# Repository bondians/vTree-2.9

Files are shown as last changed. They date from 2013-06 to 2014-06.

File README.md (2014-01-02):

vTree 2.9
==========

This is mokus's version of the XBee-controlled RGB LED floodlight.  This repository includes the latest hardware and firmware designs.  If cayuse is interested the firmware can be fairly easily ported to his hardware as well.

Hardware
=========

In the `schematics/` directory, there are several gEDA schematics and layouts.  The main ones of interest are:

 * `schematics/standalone-power-section`:  This is a small board with a power regulator, 3 MOSFETS, and associated resistors and capacitors.  Just add an MCU and IR receiver of your choice.

 * `schematics/xmega-xbee-rgb-led`: This is mokus's current prototype - it's a single board with all the stuff from the "standalone power section" plus an XMEGA 8E5 and headers to directly attach an XBee (non-pro only, for space reasons).

For cost reasons, all current hardware makes a pretty heinous compromise - the 3 LED channels share a single driver.  The plan is to attempt to correct for this in software (this is partially implemented and looks tractable).  If that proves infeasible, future versions may be modified to use a voltage-regulated supply and a separate 3-channel current regulation stage.

Firmware
=========

The firmware currently targets only the XMEGA E5, but should be pretty easy to port to any AVR.  It is also currently pretty simple, since I'm still mostly working on getting the hardware built.  It has 2 control inputs - an XBee module and an IR receiver.  The XBee (series 1 or 2, both work) is expected to be configured for 9600 baud, 8N1, API mode with escape codes.  The IR codes are hard-coded and the current values are probably not useful to anyone but me.

The XBee message format is very simple (and very likely to change soon).  Any message with 6 or more bytes is interpreted as a command to set the R, G and B channels (respectively) to the first 6 bytes of the message, interpreted as a series of big-endian 16-bit words.

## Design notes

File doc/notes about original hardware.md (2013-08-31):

Some notes about the original hardware we're hacking up here...

Parts on the control board:

- SOIC-8 I2C EEPROM, marked:

        Atmel306
        24C02BN
        SU27 D

- Unmarked SOIC-8 IC
    (presumed MCU, not able to identify by pinout)

- n-channel enhancement mode mosfet (si2302)
    - marked `A2sHB`
    - smd "331" (330 ohm) resistor on gate of each, in series to mcu
    - no pull-down on gates... the thing flashes when plugged in

- regulator
    - marked `78L05 d3`
    - rated 5V, 100mA
    - 100 uF on input, 47 uF on output

- IR receiver
    - very clearly marked `3144S` but i can't find a datasheet or any other info about it
    - mated to a ~4" cable via a very small pcb inside some heat-shrink (pcb is purely structural, no logic or additional components)
    - works at 3.3v

- Other parts:
    - capacitor, 12 pF
    - capacitor, 1 nF
    - capacitor, 100 nF
    - resistor, 15 ohm (appears to be 2W carbon-film type, or maybe 5W metal-film)
    - inductor/ferrite bead (probably, it's in series from regulator output to 5v power)

Other observations (some stuff i could see with my multimeter, and some calculations based on the assumption that the driver's claimed 600mA current regulation is correct):

 - light off:
    - ~48 kHz ripple (at + side of LED module)
    - input voltage 12.12V

- light full-on white:
    - input voltage 8.75
    - 155.3 Hz pwm on red, green - blue appears to be fully on
    - voltage drop across:
        - red:   6.21
        - R+red: 8.63
        - R:     2.42
        - green: 8.63
        - blue:  8.65
    - calculations:
        - total power:
            5.25 W
        - current through:
            - R, red:   161 mA
        - power through R: 390 mW
    
- light full-red:
    - ~ 138 kHz ripple
    - 155.3 Hz pwm on red, ripple on others
    - input voltage 11.68
    - voltage drop across:
        - red:   6.72
        - R+red: 11.45
        - green: 0.00
        - blue:  0.00
    - calculations:
        - total power (assuming 100% duty, which I think is wrong):
            7 W
        - current through:
            - R, red:   315.33333 mA
        - power through R: 1.49 W

- light full-green:
    - ~ 100 kHz ripple
    - 155.3 Hz pwm on green, ripple on others
    - input voltage 10.15
    - voltage drop across:
        - red:   4.51
        - R+red: 4.50
        - green: 9.94
        - blue:  1.76
    - calculations:
        - total power (assuming 100% duty, which I think is wrong):
            6.09 W

- light full-blue:
    - ~ 100 kHz ripple
    - momentary 155.3 Hz pwm on blue, then 0Hz (ripple on others).
    - input voltage 9.82
    - voltage drop across:
        - red:   3.68
        - R+red: 3.60
        - green: 6.28
        - blue:  9.68
    - calculations:
        - total power: 5.892 W

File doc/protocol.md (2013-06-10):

Current protocol (will likely change...):

1 byte 'sync' (or hardware-level break), 1 byte size (excluding size, sync and crc), 1-256 bytes payload (size 0 is interpreted as 256), 2 bytes CRC.  CRC polynomial TBD, prolly whatever's in the AVR libs.

overview of payload types:

    * enumerate: need to work out details, but there must be an enumeration scheme whereby the host, when initializing, can discover all lights and any new light, when initializing, will report itself to the host.  Net effect being that the host will always know what devices are attached.  'Device number', used in many other message types, is established here (it may be negotiated or, more likely, it may be an NVRAM-stored attribute of the device).  Devices also should be able to determine whether there is a host present.  Simplest scheme would probably be for all devices to send a heartbeat, with "host" devices using a different range of device numbers (or just one specified device number if it's fair to assume there is always at most one host).

    * get device info: given device number, device replies with immutable info about itself such as number of channels (maybe also topology info about physical groupings), basic description of what each channel does (color/hue/sat/brightness/generic pwm load/etc), etc.
    
    * set channel address: given a serial number/chan number pair, assigns a logical address.  This address should be remembered by the device across resets.
    
    * query channel address: given serial number/chan number pair, device reports what address is currently assigned to that channel.
    
    * set channel values: given a collection of channel addresses and/or device/chan number pairs, and a corresponding collection of channel levels, set the specified channels to the specified levels.
    
    * query channel value: given a channel address or device/chan pair, get the current value of the specified channel

    * IR code received: when a device receives an IR code, it sends its device number and the code.

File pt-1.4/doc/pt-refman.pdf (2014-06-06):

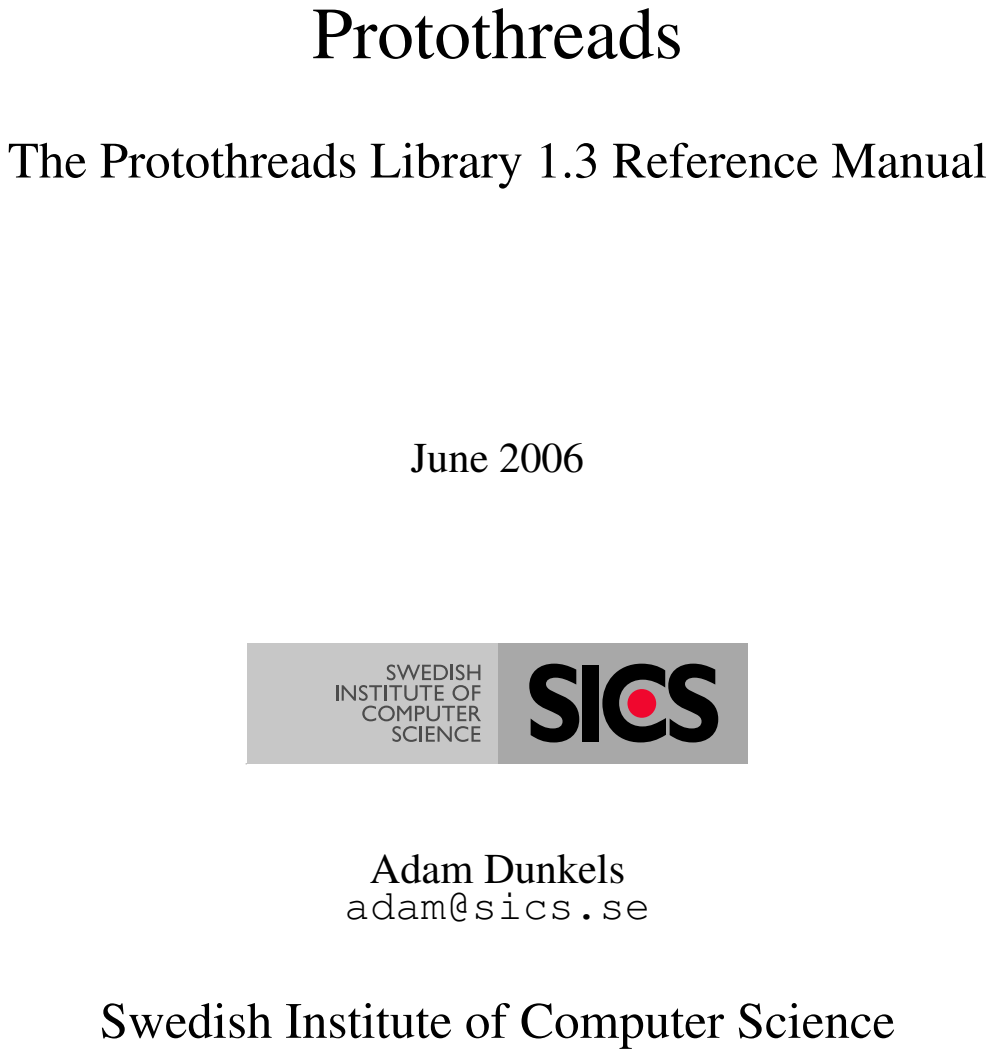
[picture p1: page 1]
Protothreads; June 2006

The Protothreads Library 1.3 Reference Manual

Adam Dunkels
adam@sics.se

Swedish Institute of Computer Science

CONTENTS | 1

## Contents

1 The Protothreads Library | 1
2 The Protothreads Library 1.4 Module Index | 3
3 The Protothreads Library 1.4 Hierarchical Index | 3
4 The Protothreads Library 1.4 Data Structure Index | 4
5 The Protothreads Library 1.4 File Index | 4
6 The Protothreads Library 1.4 Module Documentation | 4
7 The Protothreads Library 1.4 Data Structure Documentation | 25
8 The Protothreads Library 1.4 File Documentation | 25

## 1 The Protothreads Library

Author:
Adam Dunkels <adam@sics.se>

Protothreads are a type of lightweight stackless threads designed for severly memory constrained systems such as deeply embedded systems or sensor network nodes. Protothreads provides linear code execution for event-driven systems implemented in C. Protothreads can be used with or without an RTOS.

Protothreads are a extremely lightweight, stackless type of threads that provides a blocking context on top of an event-driven system, without the overhead of per-thread stacks. The purpose of protothreads is to implement sequential flow of control without complex state machines or full multi-threading. Protothreads provides conditional blocking inside C functions.

Main features:

- No machine specific code - the protothreads library is pure C
- Does not use error-prone functions such as longjmp()
- Very small RAM overhead - only two bytes per protothread
- Can be used with or without an OS
- Provides blocking wait without full multi-threading or stack-switching

Examples applications:

- Memory constrained systems
- Event-driven protocol stacks

Generated on Mon Oct 2 10:06:29 2006 for The Protothreads Library 1.4 by Doxygen

1.1 Authors | 2
- Deeply embedded systems
- Sensor network nodes

See also:
Example programs
Protothreads API documentation

The protothreads library is released under a BSD-style license that allows for both non-commercial and commercial usage. The only requirement is that credit is given.

More information and new version of the code can be found at the Protothreads homepage:

http://www.sics.se/∼adam/pt/ (http://www.sics.se/~adam/pt/)

### 1.1 Authors

The protothreads library was written by Adam Dunkels <adam@sics.se> with support from Oliver
Schmidt <ol.sc@web.de>.

### 1.2 Using protothreads

Using protothreads in a project is easy: simply copy the files pt.h, lc.h and lc-switch.h into the include files directory of the project, and #include "pt.h" in all files that should use protothreads.

### 1.3 Protothreads

Protothreads are a extremely lightweight, stackless threads that provides a blocking context on top of an event-driven system, without the overhead of per-thread stacks. The purpose of protothreads is to implement sequential flow of control without using complex state machines or full multi-threading. Protothreads provides conditional blocking inside a C function.

In memory constrained systems, such as deeply embedded systems, traditional multi-threading may have a too large memory overhead. In traditional multi-threading, each thread requires its own stack, that typically is over-provisioned. The stacks may use large parts of the available memory.

The main advantage of protothreads over ordinary threads is that protothreads are very lightweight: a protothread does not require its own stack. Rather, all protothreads run on the same stack and context switching is done by stack rewinding. This is advantageous in memory constrained systems, where a stack for a thread might use a large part of the available memory. A protothread only requires only two bytes of memory per protothread. Moreover, protothreads are implemented in pure C and do not require any machine-specific assembler code.

A protothread runs within a single C function and cannot span over other functions. A protothread may call normal C functions, but cannot block inside a called function. Blocking inside nested function calls is instead made by spawning a separate protothread for each potentially blocking function. The advantage of this approach is that blocking is explicit: the programmer knows exactly which functions that block that which functions the never blocks.

Protothreads are similar to asymmetric co-routines. The main difference is that co-routines uses a separate stack for each co-routine, whereas protothreads are stackless. The most similar mechanism to protothreads are Python generators. These are also stackless constructs, but have a different purpose. Protothreads provides blocking contexts inside a C function, whereas Python generators provide multiple exit points from a generator function.

1.4 Local variables | 3

### 1.4 Local variables

Note:
Because protothreads do not save the stack context across a blocking call, local variables are not preserved when the protothread blocks. This means that local variables should be used with utmost care - if in doubt, do not use local variables inside a protothread!

### 1.5 Scheduling

A protothread is driven by repeated calls to the function in which the protothread is running. Each time the function is called, the protothread will run until it blocks or exits. Thus the scheduling of protothreads is done by the application that uses protothreads.

### 1.6 Implementation

Protothreads are implemented using local continuations. A local continuation represents the current state of execution at a particular place in the program, but does not provide any call history or local variables. A local continuation can be set in a specific function to capture the state of the function. After a local continuation has been set can be resumed in order to restore the state of the function at the point where the local continuation was set.

Local continuations can be implemented in a variety of ways:

1. by using machine specific assembler code,
2. by using standard C constructs, or
3. by using compiler extensions.

The first way works by saving and restoring the processor state, except for stack pointers, and requires between 16 and 32 bytes of memory per protothread. The exact amount of memory required depends on the architecture.

The standard C implementation requires only two bytes of state per protothread and utilizes the C switch() statement in a non-obvious way that is similar to Duff’s device. This implementation does, however, impose a slight restriction to the code that uses protothreads: a protothread cannot perform a blocking wait (PT_WAIT_UNTIL() or PT_YIELD()) inside a switch() statement.

Certain compilers has C extensions that can be used to implement protothreads. GCC supports label pointers that can be used for this purpose. With this implementation, protothreads require 4 bytes of RAM per protothread.

## 2 The Protothreads Library 1.4 Module Index

### 2.1 The Protothreads Library 1.4 Modules

Here is a list of all modules:

Protothreads | 4
Protothread semaphores | 20
Local continuations | 23

3 The Protothreads Library 1.4 Hierarchical Index | 4
Examples | 9

## 3 The Protothreads Library 1.4 Hierarchical Index

### 3.1 The Protothreads Library 1.4 Class Hierarchy

This inheritance list is sorted roughly, but not completely, alphabetically:

pt | 25
pt_sem | 25

## 4 The Protothreads Library 1.4 Data Structure Index

### 4.1 The Protothreads Library 1.4 Data Structures

Here are the data structures with brief descriptions:

pt | 25
pt_sem | 25

## 5 The Protothreads Library 1.4 File Index

### 5.1 The Protothreads Library 1.4 File List

Here is a list of all documented files with brief descriptions:

lc-addrlabels.h (Implementation of local continuations based on the "Labels as values" fea-
ture of gcc ) | 25
lc-switch.h (Implementation of local continuations based on switch() statment ) | 26
lc.h (Local continuations ) | 26
pt-sem.h (Couting semaphores implemented on protothreads ) | 27
pt.h (Protothreads implementation ) | 27

## 6 The Protothreads Library 1.4 Module Documentation

### 6.1 Protothreads

### 6.1.1 Detailed Description

Protothreads are implemented in a single header file, pt.h, which includes the local continuations header file, lc.h.

6.1 Protothreads | 5

This file in turn includes the actual implementation of local continuations, which typically also is contained in a single header file.

Files

- file pt.h

Protothreads implementation.

Modules

- Protothread semaphores

This module implements counting semaphores on top of protothreads.

- Local continuations

Local continuations form the basis for implementing protothreads.

Data Structures

- struct pt

Initialization

- #define PT_INIT(pt)

Initialize a protothread.

Declaration and definition

- #define PT_THREAD(name_args)

Declaration of a protothread.

- #define PT_BEGIN(pt)

Declare the start of a protothread inside the C function implementing the protothread.

- #define PT_END(pt)

Declare the end of a protothread.

Blocked wait

- #define PT_WAIT_UNTIL(pt, condition)

Block and wait until condition is true.

- #define PT_WAIT_WHILE(pt, cond)

Block and wait while condition is true.

6.1 Protothreads | 6

Hierarchical protothreads

- #define PT_WAIT_THREAD(pt, thread)

Block and wait until a child protothread completes.

- #define PT_SPAWN(pt, child, thread)

Spawn a child protothread and wait until it exits.

Exiting and restarting

- #define PT_RESTART(pt)

Restart the protothread.

- #define PT_EXIT(pt)

Exit the protothread.

Calling a protothread

- #define PT_SCHEDULE(f)

Schedule a protothread.

Yielding from a protothread

- #define PT_YIELD(pt)

Yield from the current protothread.

- #define PT_YIELD_UNTIL(pt, cond)

Yield from the protothread until a condition occurs.

Defines

- #define PT_WAITING 0
- #define PT_YIELDED 1
- #define PT_EXITED 2
- #define PT_ENDED 3

### 6.1.2 Define Documentation

6.1.2.1 #define PT_BEGIN(pt)

Declare the start of a protothread inside the C function implementing the protothread.

This macro is used to declare the starting point of a protothread. It should be placed at the start of the function in which the protothread runs. All C statements above the PT_BEGIN() invokation will be executed each time the protothread is scheduled.

6.1 Protothreads | 7

Parameters:
pt A pointer to the protothread control structure.

Definition at line 115 of file pt.h.

6.1.2.2 #define PT_END(pt)

Declare the end of a protothread.

This macro is used for declaring that a protothread ends. It must always be used together with a matching PT_BEGIN() macro.

Parameters:
pt A pointer to the protothread control structure.

Definition at line 127 of file pt.h.

6.1.2.3 #define PT_EXIT(pt)

Exit the protothread.

This macro causes the protothread to exit. If the protothread was spawned by another protothread, the parent protothread will become unblocked and can continue to run.

Parameters:
pt A pointer to the protothread control structure.

Definition at line 246 of file pt.h.

6.1.2.4 #define PT_INIT(pt)

Initialize a protothread.

Initializes a protothread. Initialization must be done prior to starting to execute the protothread.

Parameters:
pt A pointer to the protothread control structure.

See also:
PT_SPAWN()

Definition at line 80 of file pt.h.

6.1.2.5 #define PT_RESTART(pt)

Restart the protothread.

This macro will block and cause the running protothread to restart its execution at the place of the PT_-BEGIN() call.

Parameters:
pt A pointer to the protothread control structure.

Definition at line 229 of file pt.h.

6.1 Protothreads | 8

6.1.2.6 #define PT_SCHEDULE(f)

Schedule a protothread.

This function shedules a protothread. The return value of the function is non-zero if the protothread is running or zero if the protothread has exited.

Parameters:
f The call to the C function implementing the protothread to be scheduled

Definition at line 271 of file pt.h.

6.1.2.7 #define PT_SPAWN(pt, child, thread)

Spawn a child protothread and wait until it exits.

This macro spawns a child protothread and waits until it exits. The macro can only be used within a protothread.

Parameters:
pt A pointer to the protothread control structure.
child A pointer to the child protothread’s control structure. thread The child protothread with arguments

Definition at line 206 of file pt.h.

6.1.2.8 #define PT_THREAD(name_args)

Declaration of a protothread.

This macro is used to declare a protothread. All protothreads must be declared with this macro.

Parameters:
name_args The name and arguments of the C function implementing the protothread.

Definition at line 100 of file pt.h.

6.1.2.9 #define PT_WAIT_THREAD(pt, thread)

Block and wait until a child protothread completes.

This macro schedules a child protothread. The current protothread will block until the child protothread completes.

Note:
The child protothread must be manually initialized with the PT_INIT() function before this function is used.

Parameters:
pt A pointer to the protothread control structure.
thread The child protothread with arguments

See also:
PT_SPAWN()

Definition at line 192 of file pt.h.

6.2 Examples | 9

6.1.2.10 #define PT_WAIT_UNTIL(pt, condition)

Block and wait until condition is true.

This macro blocks the protothread until the specified condition is true.

Parameters:
pt A pointer to the protothread control structure.
condition The condition.

Definition at line 148 of file pt.h.

6.1.2.11 #define PT_WAIT_WHILE(pt, cond)

Block and wait while condition is true.

This function blocks and waits while condition is true. See PT_WAIT_UNTIL().

Parameters:
pt A pointer to the protothread control structure.
cond The condition.

Definition at line 167 of file pt.h.

6.1.2.12 #define PT_YIELD(pt)

Yield from the current protothread.

This function will yield the protothread, thereby allowing other processing to take place in the system.

Parameters:
pt A pointer to the protothread control structure.

Definition at line 290 of file pt.h.

6.1.2.13 #define PT_YIELD_UNTIL(pt, cond)

Yield from the protothread until a condition occurs.

Parameters:
pt A pointer to the protothread control structure.
cond The condition.

This function will yield the protothread, until the specified condition evaluates to true.

Definition at line 310 of file pt.h.

### 6.2 Examples

### 6.2.1 A small example

This first example shows a very simple program: two protothreads waiting for each other to toggle two flags. The code illustrates how to write protothreads code, how to initialize protothreads, and how to schedule them.

6.2 Examples | 10

/**
* This is a very small example that shows how to use
* protothreads. The program consists of two protothreads that wait * for each other to toggle a variable.
*/

/* We must always include pt.h in our protothreads code. */ #include "pt.h"

#include <stdio.h> /* For printf(). */

/* Two flags that the two protothread functions use. */ static int protothread1_flag, protothread2_flag;

/**
* The first protothread function. A protothread function must always * return an integer, but must never explicitly return - returning is * performed inside the protothread statements.

*
* The protothread function is driven by the main loop further down in * the code.
*/
static int
protothread1(struct pt *pt)
{
/* A protothread function must begin with PT_BEGIN() which takes a pointer to a struct pt. */
PT_BEGIN(pt);

/* We loop forever here. */
while(1) {
/* Wait until the other protothread has set its flag. */ PT_WAIT_UNTIL(pt, protothread2_flag != 0); printf("Protothread 1 running\n");

/* We then reset the other protothread’s flag, and set our own flag so that the other protothread can run. */ protothread2_flag = 0;
protothread1_flag = 1;

/* And we loop. */
}

/* All protothread functions must end with PT_END() which takes a pointer to a struct pt. */
PT_END(pt);
}

/**
* The second protothread function. This is almost the same as the * first one.
*/
static int
protothread2(struct pt *pt) {
PT_BEGIN(pt);

while(1) {
/* Let the other protothread run. */
protothread2_flag = 1;

/* Wait until the other protothread has set its flag. */ PT_WAIT_UNTIL(pt, protothread1_flag != 0); printf("Protothread 2 running\n");

/* We then reset the other protothread’s flag. */ protothread1_flag = 0;

6.2 Examples | 11

/* And we loop. */
}
PT_END(pt);
}

/**
* Finally, we have the main loop. Here is where the protothreads are * initialized and scheduled. First, however, we define the
* protothread state variables pt1 and pt2, which hold the state of * the two protothreads.
*/
static struct pt pt1, pt2;
int
main(void)
{
/* Initialize the protothread state variables with PT_INIT(). */ PT_INIT(&pt1);
PT_INIT(&pt2);

/*
* Then we schedule the two protothreads by repeatedly calling their * protothread functions and passing a pointer to the protothread
* state variables as arguments.
*/
while(1) {
protothread1(&pt1);
protothread2(&pt2);
}
}

### 6.2.2 A code-lock

This example shows how to implement a simple code lock - the kind of device that is placed next to doors and that you have to push a four digit number into in order to unlock the door.

The code lock waits for key presses from a numeric keyboard and if the correct code is entered, the lock is unlocked. There is a maximum time of one second between each key press, and after the correct code has been entered, no more keys must be pressed for 0.5 seconds before the lock is opened.

/*
* Copyright (c) 2004-2005, Swedish Institute of Computer Science.
* All rights reserved.

*
* Redistribution and use in source and binary forms, with or without * modification, are permitted provided that the following conditions * are met:
* 1. Redistributions of source code must retain the above copyright
* | notice, this list of conditions and the following disclaimer.
* 2. Redistributions in binary form must reproduce the above copyright
* | notice, this list of conditions and the following disclaimer in the
* | documentation and/or other materials provided with the distribution.
* 3. Neither the name of the Institute nor the names of its contributors
* | may be used to endorse or promote products derived from this software
* | without specific prior written permission.

*
* THIS SOFTWARE IS PROVIDED BY THE INSTITUTE AND CONTRIBUTORS ‘‘AS IS’’ AND * ANY EXPRESS OR IMPLIED WARRANTIES, INCLUDING, BUT NOT LIMITED TO, THE
* IMPLIED WARRANTIES OF MERCHANTABILITY AND FITNESS FOR A PARTICULAR PURPOSE * ARE DISCLAIMED. IN NO EVENT SHALL THE INSTITUTE OR CONTRIBUTORS BE LIABLE * FOR ANY DIRECT, INDIRECT, INCIDENTAL, SPECIAL, EXEMPLARY, OR CONSEQUENTIAL * DAMAGES (INCLUDING, BUT NOT LIMITED TO, PROCUREMENT OF SUBSTITUTE GOODS
* OR SERVICES; LOSS OF USE, DATA, OR PROFITS; OR BUSINESS INTERRUPTION)
* HOWEVER CAUSED AND ON ANY THEORY OF LIABILITY, WHETHER IN CONTRACT, STRICT * LIABILITY, OR TORT (INCLUDING NEGLIGENCE OR OTHERWISE) ARISING IN ANY WAY

6.2 Examples | 12

* OUT OF THE USE OF THIS SOFTWARE, EVEN IF ADVISED OF THE POSSIBILITY OF * SUCH DAMAGE.

*
* This file is part of the protothreads library.

*
* Author: Adam Dunkels <adam@sics.se>

*
* $Id: example-codelock.c,v 1.5 2005/10/06 07:57:08 adam Exp $ */

/*

*
* This example shows how to implement a simple code lock. The code * lock waits for key presses from a numeric keyboard and if the
* correct code is entered, the lock is unlocked. There is a maximum * time of one second between each key press, and after the correct
* code has been entered, no more keys must be pressed for 0.5 seconds * before the lock is opened.

*
* This is an example that shows two things:
* - how to implement a code lock key input mechanism, and
* - how to implement a sequential timed routine.

*
* The program consists of two protothreads, one that implements the * code lock reader and one that implements simulated keyboard input.

*
*
*/

#ifdef _WIN32

#include <windows.h>

#else

#include <unistd.h>

#include <sys/time.h>

#endif

#include <stdio.h>

#include "pt.h"

/*---------------------------------------------------------------------------*/ /*
* The following definitions are just for the simple timer library
* used in this example. The actual implementation of the functions
* can be found at the end of this file.
*/
struct timer { int start, interval; };
static int timer_expired(struct timer *t);
static void timer_set(struct timer *t, int usecs); /*---------------------------------------------------------------------------*/ /*
* This example uses two timers: one for the code lock protothread and
* one for the simulated key input protothread.
*/
static struct timer codelock_timer, input_timer; /*---------------------------------------------------------------------------*/ /*
* This is the code that has to be entered.
*/
static const char code[4] = {’1’, ’4’, ’2’, ’3’}; /*---------------------------------------------------------------------------*/ /*
* This example has two protothread and therefor has two protothread
* control structures of type struct pt. These are initialized with
* PT_INIT() in the main() function below.
*/
static struct pt codelock_pt, input_pt; /*---------------------------------------------------------------------------*/

6.2 Examples | 13

/*
* The following code implements a simple key input. Input is made
* with the press_key() function, and the function key_pressed()
* checks if a key has been pressed. The variable "key" holds the
* latest key that was pressed. The variable "key_pressed_flag" is set * when a key is pressed and cleared when a key press is checked.
*/
static char key, key_pressed_flag;

static void
press_key(char k)
{
printf("--- Key ’%c’ pressed\n", k); key = k;
key_pressed_flag = 1;
}

static int
key_pressed(void)
{
if(key_pressed_flag != 0) { key_pressed_flag = 0;
return 1;
}
return 0;
}
/*---------------------------------------------------------------------------*/ /*
* Declaration of the protothread function implementing the code lock
* logic. The protothread function is declared using the PT_THREAD()
* macro. The function is declared with the "static" keyword since it * is local to this file. The name of the function is codelock_thread * and it takes one argument, pt, of the type struct pt.

*
*/
static
PT_THREAD(codelock_thread(struct pt *pt))
{
/* This is a local variable that holds the number of keys that have * been pressed. Note that it is declared with the "static" keyword * to make sure that the variable is *not* allocated on the stack. */
static int keys;

/*
* Declare the beginning of the protothread. */
PT_BEGIN(pt);

/*
* We’ll let the protothread loop until the protothread is * expliticly exited with PT_EXIT().
*/
while(1) {

/*
* We’ll be reading key presses until we get the right amount of * correct keys.
*/
for(keys = 0; keys < sizeof(code); ++keys) {

/*
* If we haven’t gotten any keypresses, we’ll simply wait for one. */
if(keys == 0) {

/*

6.2 Examples | 14

* The PT_WAIT_UNTIL() function will block until the condition * key_pressed() is true.
*/
PT_WAIT_UNTIL(pt, key_pressed());
} else {

/*
* If the "key" variable was larger than zero, we have already * gotten at least one correct key press. If so, we’ll not
* only wait for the next key, but we’ll also set a timer that * expires in one second. This gives the person pressing the * keys one second to press the next key in the code.
*/
timer_set(&codelock_timer, 1000);

/*
* The following statement shows how complex blocking
* conditions can be easily expressed with protothreads and
* the PT_WAIT_UNTIL() function.
*/
PT_WAIT_UNTIL(pt, key_pressed() || timer_expired(&codelock_timer));

/*
* If the timer expired, we should break out of the for() loop
* and start reading keys from the beginning of the while(1) * loop instead.
*/
if(timer_expired(&codelock_timer)) {
printf("Code lock timer expired.\n");

/*
* Break out from the for() loop and start from the * beginning of the while(1) loop.
*/
break;
}
}

/*
* Check if the pressed key was correct.
*/
if(key != code[keys]) {
printf("Incorrect key ’%c’ found\n", key);
/*
* Break out of the for() loop since the key was incorrect. */
break;
} else {
printf("Correct key ’%c’ found\n", key); }
}

/*
* Check if we have gotten all keys.
*/
if(keys == sizeof(code)) {
printf("Correct code entered, waiting for 500 ms before unlocking.\n");

/*
* Ok, we got the correct code. But to make sure that the code
* was not just a fluke of luck by an intruder, but the correct * code entered by a person that knows the correct code, we’ll * wait for half a second before opening the lock. If another * key is pressed during this time, we’ll assume that it was a * fluke of luck that the correct code was entered the first * time.
*/

6.2 Examples | 15

timer_set(&codelock_timer, 500);
PT_WAIT_UNTIL(pt, key_pressed() || timer_expired(&codelock_timer));

/*
* If we continued from the PT_WAIT_UNTIL() statement without
* the timer expired, we don’t open the lock.
*/
if(!timer_expired(&codelock_timer)) {
printf("Key pressed during final wait, code lock locked again.\n"); } else {

/*
* If the timer expired, we’ll open the lock and exit from the * protothread.
*/
printf("Code lock unlocked.\n");
PT_EXIT(pt);
}
}
}

/*
* Finally, we’ll mark the end of the protothread. */
PT_END(pt);
}
/*---------------------------------------------------------------------------*/ /*
* This is the second protothread in this example. It implements a
* simulated user pressing the keys. This illustrates how a linear
* sequence of timed instructions can be implemented with
* protothreads.
*/
static
PT_THREAD(input_thread(struct pt *pt)) {
PT_BEGIN(pt);

printf("Waiting 1 second before entering first key.\n");

timer_set(&input_timer, 1000);
PT_WAIT_UNTIL(pt, timer_expired(&input_timer));

press_key(’1’);

timer_set(&input_timer, 100); PT_WAIT_UNTIL(pt, timer_expired(&input_timer));

press_key(’2’);

timer_set(&input_timer, 100); PT_WAIT_UNTIL(pt, timer_expired(&input_timer));

press_key(’3’);

timer_set(&input_timer, 2000); PT_WAIT_UNTIL(pt, timer_expired(&input_timer));

press_key(’1’);

timer_set(&input_timer, 200); PT_WAIT_UNTIL(pt, timer_expired(&input_timer));

press_key(’4’);

timer_set(&input_timer, 200); PT_WAIT_UNTIL(pt, timer_expired(&input_timer));

6.2 Examples | 16

press_key(’2’);

timer_set(&input_timer, 2000); PT_WAIT_UNTIL(pt, timer_expired(&input_timer));

press_key(’3’);

timer_set(&input_timer, 200); PT_WAIT_UNTIL(pt, timer_expired(&input_timer));

press_key(’1’);

timer_set(&input_timer, 200); PT_WAIT_UNTIL(pt, timer_expired(&input_timer));

press_key(’4’);

timer_set(&input_timer, 200); PT_WAIT_UNTIL(pt, timer_expired(&input_timer));

press_key(’2’);

timer_set(&input_timer, 100); PT_WAIT_UNTIL(pt, timer_expired(&input_timer));

press_key(’3’);

timer_set(&input_timer, 100); PT_WAIT_UNTIL(pt, timer_expired(&input_timer));

press_key(’4’);

timer_set(&input_timer, 1500); PT_WAIT_UNTIL(pt, timer_expired(&input_timer));

press_key(’1’);

timer_set(&input_timer, 300); PT_WAIT_UNTIL(pt, timer_expired(&input_timer));

press_key(’4’);

timer_set(&input_timer, 400); PT_WAIT_UNTIL(pt, timer_expired(&input_timer));

press_key(’2’);

timer_set(&input_timer, 500); PT_WAIT_UNTIL(pt, timer_expired(&input_timer));

press_key(’3’);

timer_set(&input_timer, 2000); PT_WAIT_UNTIL(pt, timer_expired(&input_timer));

PT_END(pt);
}
/*---------------------------------------------------------------------------*/ /*
* This is the main function. It initializes the two protothread
* control structures and schedules the two protothreads. The main
* function returns when the protothread the runs the code lock exits. */
int
main(void)
{

6.2 Examples | 17

/*
* Initialize the two protothread control structures. */
PT_INIT(&input_pt);
PT_INIT(&codelock_pt);

/*
* Schedule the two protothreads until the codelock_thread() exits. */
while(PT_SCHEDULE(codelock_thread(&codelock_pt))) { PT_SCHEDULE(input_thread(&input_pt));

/*
* When running this example on a multitasking system, we must
* give other processes a chance to run too and therefore we call * usleep() resp. Sleep() here. On a dedicated embedded system, * we usually do not need to do this.
*/
#ifdef _WIN32

Sleep(0);
#else

usleep(10);
#endif

}

return 0;
}
/*---------------------------------------------------------------------------*/ /*
* Finally, the implementation of the simple timer library follows.
*/
#ifdef _WIN32

static int clock_time(void)
{ return (int)GetTickCount(); }

#else /* _WIN32 */

static int clock_time(void) {
struct timeval tv;
struct timezone tz;
gettimeofday(&tv, &tz);
return tv.tv_sec * 1000 + tv.tv_usec / 1000; }

#endif /* _WIN32 */

static int timer_expired(struct timer *t)
{ return (int)(clock_time() - t->start) >= (int)t->interval; }

static void timer_set(struct timer *t, int interval)
{ t->interval = interval; t->start = clock_time(); } /*---------------------------------------------------------------------------*/

### 6.2.3 The bounded buffer with protothread semaphores

The following example shows how to implement the bounded buffer problem using the protothreads semaphore library. The example uses three protothreads: one producer() protothread that produces items, one consumer() protothread that consumes items, and one driver_thread() that schedules the producer and consumer protothreads.

Note that there is no need for a mutex to guard the add_to_buffer() and get_from_buffer() functions because of the implicit locking semantics of protothreads - a protothread will never be preempted and will never

6.2 Examples | 18

block except in an explicit PT_WAIT statement.

/*
* Copyright (c) 2004-2005, Swedish Institute of Computer Science.
* All rights reserved.

*
* Redistribution and use in source and binary forms, with or without * modification, are permitted provided that the following conditions * are met:
* 1. Redistributions of source code must retain the above copyright
* | notice, this list of conditions and the following disclaimer.
* 2. Redistributions in binary form must reproduce the above copyright
* | notice, this list of conditions and the following disclaimer in the
* | documentation and/or other materials provided with the distribution.
* 3. Neither the name of the Institute nor the names of its contributors
* | may be used to endorse or promote products derived from this software
* | without specific prior written permission.

*
* THIS SOFTWARE IS PROVIDED BY THE INSTITUTE AND CONTRIBUTORS ‘‘AS IS’’ AND * ANY EXPRESS OR IMPLIED WARRANTIES, INCLUDING, BUT NOT LIMITED TO, THE
* IMPLIED WARRANTIES OF MERCHANTABILITY AND FITNESS FOR A PARTICULAR PURPOSE * ARE DISCLAIMED. IN NO EVENT SHALL THE INSTITUTE OR CONTRIBUTORS BE LIABLE * FOR ANY DIRECT, INDIRECT, INCIDENTAL, SPECIAL, EXEMPLARY, OR CONSEQUENTIAL * DAMAGES (INCLUDING, BUT NOT LIMITED TO, PROCUREMENT OF SUBSTITUTE GOODS
* OR SERVICES; LOSS OF USE, DATA, OR PROFITS; OR BUSINESS INTERRUPTION)
* HOWEVER CAUSED AND ON ANY THEORY OF LIABILITY, WHETHER IN CONTRACT, STRICT * LIABILITY, OR TORT (INCLUDING NEGLIGENCE OR OTHERWISE) ARISING IN ANY WAY * OUT OF THE USE OF THIS SOFTWARE, EVEN IF ADVISED OF THE POSSIBILITY OF
* SUCH DAMAGE.

*
* This file is part of the protothreads library.

*
* Author: Adam Dunkels <adam@sics.se>

*
* $Id: example-buffer.c,v 1.5 2005/10/07 05:21:33 adam Exp $ */

#ifdef _WIN32

#include <windows.h>

#else

#include <unistd.h>

#endif

#include <stdio.h>

#include "pt-sem.h"

#define NUM_ITEMS 32

#define BUFSIZE 8

static int buffer[BUFSIZE]; static int bufptr;

static void
add_to_buffer(int item)
{
printf("Item %d added to buffer at place %d\n", item, bufptr); buffer[bufptr] = item;
bufptr = (bufptr + 1) % BUFSIZE;
}
static int
get_from_buffer(void)
{
int item;
item = buffer[bufptr];
printf("Item %d retrieved from buffer at place %d\n", item, bufptr);
bufptr = (bufptr + 1) % BUFSIZE;

6.2 Examples | 19

return item;
}

static int
produce_item(void)
{
static int item = 0;
printf("Item %d produced\n", item); return item++;
}

static void
consume_item(int item)
{
printf("Item %d consumed\n", item); }

static struct pt_sem full, empty;

static
PT_THREAD(producer(struct pt *pt)) {
static int produced;

PT_BEGIN(pt);

for(produced = 0; produced < NUM_ITEMS; ++produced) {

PT_SEM_WAIT(pt, &full);

add_to_buffer(produce_item());

PT_SEM_SIGNAL(pt, &empty);
}

PT_END(pt);
}

static
PT_THREAD(consumer(struct pt *pt)) {
static int consumed;

PT_BEGIN(pt);

for(consumed = 0; consumed < NUM_ITEMS; ++consumed) {

PT_SEM_WAIT(pt, &empty);

consume_item(get_from_buffer());

PT_SEM_SIGNAL(pt, &full);
}

PT_END(pt);
}

static
PT_THREAD(driver_thread(struct pt *pt))
{
static struct pt pt_producer, pt_consumer;

PT_BEGIN(pt);

PT_SEM_INIT(&empty, 0);
PT_SEM_INIT(&full, BUFSIZE);

6.3 Protothread semaphores | 20

PT_INIT(&pt_producer);
PT_INIT(&pt_consumer);

PT_WAIT_THREAD(pt, producer(&pt_producer) & consumer(&pt_consumer));

PT_END(pt);
}

int
main(void)
{
struct pt driver_pt;

PT_INIT(&driver_pt);

while(PT_SCHEDULE(driver_thread(&driver_pt))) {

/*
* When running this example on a multitasking system, we must
* give other processes a chance to run too and therefore we call * usleep() resp. Sleep() here. On a dedicated embedded system, * we usually do not need to do this.
*/
#ifdef _WIN32

Sleep(0);
#else

usleep(10);
#endif

}
return 0;
}

### 6.3 Protothread semaphores

### 6.3.1 Detailed Description

This module implements counting semaphores on top of protothreads.

Semaphores are a synchronization primitive that provide two operations: "wait" and "signal". The "wait" operation checks the semaphore counter and blocks the thread if the counter is zero. The "signal" operation increases the semaphore counter but does not block. If another thread has blocked waiting for the semaphore that is signalled, the blocked thread will become runnable again.

Semaphores can be used to implement other, more structured, synchronization primitives such as monitors and message queues/bounded buffers (see below).

The following example shows how the producer-consumer problem, also known as the bounded buffer problem, can be solved using protothreads and semaphores. Notes on the program follow after the example.

#include "pt-sem.h"

#define NUM_ITEMS 32

#define BUFSIZE 8

static struct pt_sem mutex, full, empty;

PT_THREAD(producer(struct pt *pt))
{
static int produced;

PT_BEGIN(pt);

6.3 Protothread semaphores | 21

for(produced = 0; produced < NUM_ITEMS; ++produced) {

PT_SEM_WAIT(pt, &full);

PT_SEM_WAIT(pt, &mutex);
add_to_buffer(produce_item()); PT_SEM_SIGNAL(pt, &mutex);

PT_SEM_SIGNAL(pt, &empty);
}

PT_END(pt);
}

PT_THREAD(consumer(struct pt *pt)) {
static int consumed;

PT_BEGIN(pt);

for(consumed = 0; consumed < NUM_ITEMS; ++consumed) {

PT_SEM_WAIT(pt, &empty);

PT_SEM_WAIT(pt, &mutex);
consume_item(get_from_buffer()); PT_SEM_SIGNAL(pt, &mutex);

PT_SEM_SIGNAL(pt, &full);
}

PT_END(pt);
}

PT_THREAD(driver_thread(struct pt *pt))
{
static struct pt pt_producer, pt_consumer;

PT_BEGIN(pt);

PT_SEM_INIT(&empty, 0);
PT_SEM_INIT(&full, BUFSIZE); PT_SEM_INIT(&mutex, 1);

PT_INIT(&pt_producer);
PT_INIT(&pt_consumer);

PT_WAIT_THREAD(pt, producer(&pt_producer) & consumer(&pt_consumer));

PT_END(pt);
}

The program uses three protothreads: one protothread that implements the consumer, one thread that implements the producer, and one protothread that drives the two other protothreads. The program uses three semaphores: "full", "empty" and "mutex". The "mutex" semaphore is used to provide mutual exclusion for the buffer, the "empty" semaphore is used to block the consumer is the buffer is empty, and the "full" semaphore is used to block the producer is the buffer is full.

The "driver_thread" holds two protothread state variables, "pt_producer" and "pt_consumer". It is impor-tant to note that both these variables are declared as static. If the static keyword is not used, both variables are stored on the stack. Since protothreads do not store the stack, these variables may be overwritten during a protothread wait operation. Similarly, both the "consumer" and "producer" protothreads declare their local variables as static, to avoid them being stored on the stack.

6.3 Protothread semaphores | 22

Files

- file pt-sem.h

Couting semaphores implemented on protothreads.

Data Structures

- struct pt_sem

Defines

- #define PT_SEM_INIT(s, c)

Initialize a semaphore.

- #define PT_SEM_WAIT(pt, s)

Wait for a semaphore.

- #define PT_SEM_SIGNAL(pt, s)

Signal a semaphore.

### 6.3.2 Define Documentation

6.3.2.1 #define PT_SEM_INIT(s, c)

Initialize a semaphore.

This macro initializes a semaphore with a value for the counter. Internally, the semaphores use an "unsigned int" to represent the counter, and therefore the "count" argument should be within range of an unsigned int.

Parameters:
s (struct pt_sem ∗) A pointer to the pt_sem struct representing the semaphore

c (unsigned int) The initial count of the semaphore.

Definition at line 183 of file pt-sem.h.

6.3.2.2 #define PT_SEM_SIGNAL(pt, s)

Signal a semaphore.

This macro carries out the "signal" operation on the semaphore. The signal operation increments the counter inside the semaphore, which eventually will cause waiting protothreads to continue executing.

Parameters:
pt (struct pt ∗) A pointer to the protothread (struct pt) in which the operation is executed.

s (struct pt_sem ∗) A pointer to the pt_sem struct representing the semaphore

Definition at line 222 of file pt-sem.h.

6.4 Local continuations | 23

6.3.2.3 #define PT_SEM_WAIT(pt, s)

Wait for a semaphore.

This macro carries out the "wait" operation on the semaphore. The wait operation causes the protothread to block while the counter is zero. When the counter reaches a value larger than zero, the protothread will continue.

Parameters:
pt (struct pt ∗) A pointer to the protothread (struct pt) in which the operation is executed.

s (struct pt_sem ∗) A pointer to the pt_sem struct representing the semaphore

Definition at line 201 of file pt-sem.h.

### 6.4 Local continuations

### 6.4.1 Detailed Description

Local continuations form the basis for implementing protothreads.

A local continuation can be set in a specific function to capture the state of the function. After a local continuation has been set can be resumed in order to restore the state of the function at the point where the local continuation was set.

Files

- file lc.h

Local continuations.

- file lc-switch.h

Implementation of local continuations based on switch() statment.

- file lc-addrlabels.h

Implementation of local continuations based on the "Labels as values" feature of gcc.

Defines

- #define LC_INIT(lc)

Initialize a local continuation.

- #define LC_SET(lc)

Set a local continuation.

- #define LC_RESUME(lc)

Resume a local continuation.

- #define LC_END(lc)

Mark the end of local continuation usage.

- #define LC_INIT(s) s = 0;

6.4 Local continuations | 24
- #define LC_RESUME(s) switch(s) { case 0:
- #define LC_SET(s) s = __LINE__; case __LINE__:
- #define LC_END(s) }
- #define LC_INIT(s) s = NULL
- #define LC_RESUME(s)
- #define LC_CONCAT2(s1, s2) s1##s2
- #define LC_CONCAT(s1, s2) LC_CONCAT2(s1, s2)
- #define LC_SET(s)
- #define LC_END(s)

Typedefs

- typedef unsigned short lc_t

The local continuation type.

- typedef void ∗ lc_t

### 6.4.2 Define Documentation

6.4.2.1 #define LC_END(lc)

Mark the end of local continuation usage.

The end operation signifies that local continuations should not be used any more in the function. This operation is not needed for most implementations of local continuation, but is required by a few implementations.

Definition at line 108 of file lc.h.

6.4.2.2 #define LC_INIT(lc)

Initialize a local continuation.

This operation initializes the local continuation, thereby unsetting any previously set continuation state.

Definition at line 71 of file lc.h.

6.4.2.3 #define LC_RESUME(lc)

Resume a local continuation.

The resume operation resumes a previously set local continuation, thus restoring the state in which the function was when the local continuation was set. If the local continuation has not been previously set, the resume operation does nothing.

Definition at line 96 of file lc.h.

6.4.2.4 #define LC_SET(lc)

Set a local continuation.

The set operation saves the state of the function at the point where the operation is executed. As far as the set operation is concerned, the state of the function does not include the call-stack or local (automatic) variables, but only the program counter and such CPU registers that needs to be saved.

Definition at line 84 of file lc.h.

7 The Protothreads Library 1.4 Data Structure Documentation | 25

## 7 The Protothreads Library 1.4 Data Structure Documentation

### 7.1 pt Struct Reference

### 7.1.1 Detailed Description

Definition at line 54 of file pt.h.

Data Fields

- lc_t lc

### 7.2 pt_sem Struct Reference

### 7.2.1 Detailed Description

Definition at line 165 of file pt-sem.h.

Data Fields

- unsigned int count

## 8 The Protothreads Library 1.4 File Documentation

### 8.1 lc-addrlabels.h File Reference

### 8.1.1 Detailed Description

Implementation of local continuations based on the "Labels as values" feature of gcc.

Author:
Adam Dunkels <adam@sics.se>

This implementation of local continuations is based on a special feature of the GCC C compiler called
"labels as values". This feature allows assigning pointers with the address of the code corresponding to a
particular C label.

For more information, see the GCC documentation: http://gcc.gnu.org/onlinedocs/gcc/Labels-as-Values.html

Definition in file lc-addrlabels.h.

Defines

- #define LC_INIT(s) s = NULL
- #define LC_RESUME(s)
- #define LC_CONCAT2(s1, s2) s1##s2
- #define LC_CONCAT(s1, s2) LC_CONCAT2(s1, s2)
- #define LC_SET(s)
- #define LC_END(s)

8.2 lc-switch.h File Reference | 26

Typedefs

- typedef void ∗ lc_t

### 8.2 lc-switch.h File Reference

### 8.2.1 Detailed Description

Implementation of local continuations based on switch() statment.

Author:
Adam Dunkels <adam@sics.se>

This implementation of local continuations uses the C switch() statement to resume execution of a function somewhere inside the function’s body. The implementation is based on the fact that switch() statements are able to jump directly into the bodies of control structures such as if() or while() statmenets.

This implementation borrows heavily from Simon Tatham’s coroutines implementation in C:
http://www.chiark.greenend.org.uk/∼sgtatham/coroutines.html (http://www.chiark.greenend.org.uk/~sgtatham/coroutines.html)

Definition in file lc-switch.h.

Defines

- #define LC_INIT(s) s = 0;
- #define LC_RESUME(s) switch(s) { case 0:
- #define LC_SET(s) s = __LINE__; case __LINE__:
- #define LC_END(s) }

Typedefs

- typedef unsigned short lc_t

The local continuation type.

### 8.3 lc.h File Reference

### 8.3.1 Detailed Description

Local continuations.

Author:
Adam Dunkels <adam@sics.se>

Definition in file lc.h.

#include "lc-switch.h"

8.4 pt-sem.h File Reference | 27

Defines

- #define LC_INIT(lc)

Initialize a local continuation.

- #define LC_SET(lc)

Set a local continuation.

- #define LC_RESUME(lc)

Resume a local continuation.

- #define LC_END(lc)

Mark the end of local continuation usage.

### 8.4 pt-sem.h File Reference

### 8.4.1 Detailed Description

Couting semaphores implemented on protothreads.

Author:
Adam Dunkels <adam@sics.se>

Definition in file pt-sem.h.

#include "pt.h"

Data Structures

- struct pt_sem

Defines

- #define PT_SEM_INIT(s, c)

Initialize a semaphore.

- #define PT_SEM_WAIT(pt, s)

Wait for a semaphore.

- #define PT_SEM_SIGNAL(pt, s)

Signal a semaphore.

### 8.5 pt.h File Reference

### 8.5.1 Detailed Description

Protothreads implementation.

8.5 pt.h File Reference | 28

Author:
Adam Dunkels <adam@sics.se>

Definition in file pt.h.

#include "lc.h"

Data Structures

- struct pt

Initialization

- #define PT_INIT(pt)

Initialize a protothread.

Declaration and definition

- #define PT_THREAD(name_args)

Declaration of a protothread.

- #define PT_BEGIN(pt)

Declare the start of a protothread inside the C function implementing the protothread.

- #define PT_END(pt)

Declare the end of a protothread.

Blocked wait

- #define PT_WAIT_UNTIL(pt, condition)

Block and wait until condition is true.

- #define PT_WAIT_WHILE(pt, cond)

Block and wait while condition is true.

Hierarchical protothreads

- #define PT_WAIT_THREAD(pt, thread)

Block and wait until a child protothread completes.

- #define PT_SPAWN(pt, child, thread)

Spawn a child protothread and wait until it exits.

8.5 pt.h File Reference | 29

Exiting and restarting

- #define PT_RESTART(pt)

Restart the protothread.

- #define PT_EXIT(pt)

Exit the protothread.

Calling a protothread

- #define PT_SCHEDULE(f)

Schedule a protothread.

Yielding from a protothread

- #define PT_YIELD(pt)

Yield from the current protothread.

- #define PT_YIELD_UNTIL(pt, cond)

Yield from the protothread until a condition occurs.

Defines

- #define PT_WAITING 0
- #define PT_YIELDED 1
- #define PT_EXITED 2
- #define PT_ENDED 3

## Index

Examples,
9

lc
LC_END, 24
LC_INIT, 24
LC_RESUME, 24
LC_SET, 24
lc-addrlabels.h, 25
lc-switch.h, 26
lc.h, 26
LC_END
lc, 24
LC_INIT
lc, 24
LC_RESUME
lc, 24
LC_SET
lc, 24
Local continuations, 23

Protothread semaphores, 20 Protothreads,
4
pt, 25
PT_BEGIN,

6
PT_END,

6
PT_EXIT,

7
PT_INIT,

7
PT_RESTART,

7
PT_SCHEDULE,

7
PT_SPAWN,

8
PT_THREAD,

8
PT_WAIT_THREAD,

8
PT_WAIT_UNTIL,

8
PT_WAIT_WHILE,

9
PT_YIELD,

9
PT_YIELD_UNTIL,

9
pt-sem.h, 27
pt.h, 27
PT_BEGIN
pt,

6
PT_END
pt,

6
PT_EXIT
pt,

7
PT_INIT
pt,

7
PT_RESTART
pt,

7
PT_SCHEDULE
pt,

7
pt_sem, 25

PT_SEM_INIT
ptsem, 22
PT_SEM_SIGNAL
ptsem, 22
PT_SEM_WAIT
ptsem, 22
PT_SPAWN
pt,

8
PT_THREAD
pt,

8
PT_WAIT_THREAD
pt,
8
PT_WAIT_UNTIL
pt,

8
PT_WAIT_WHILE
pt,

9
PT_YIELD
pt,

9
PT_YIELD_UNTIL
pt,

9
ptsem
PT_SEM_INIT, 22
PT_SEM_SIGNAL, 22
PT_SEM_WAIT, 22

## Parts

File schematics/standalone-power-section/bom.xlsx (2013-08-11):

Ref | qty | Description | P/N | Supplier | MOQ | price breaks: | 1 | 10 | 50 | 100 | qty produced: | 3 |  | total cost | 8.82
 |  |  |  |  |  |  |  |  |  |  | part qty | per-part | total | total per unit | 2.94
U1 | 1 | 3.3V regulator | LD2981ABU33TR | Mouser | 1 |  | 0.69 | 0.61 | 0.61 | 0.466 | 3 | 0.69 | 2.07
C1 | 1 | regulator input decoupling | AVE107M16X16T-F | Mouser | 1 |  | 0.12 | 0.12 | 0.11 | 0.092 | 3 | 0.12 | 0.36
C2 | 1 | regulator output decoupling | AVE476M06C12T-F | Mouser | 1 |  | 0.1 | 0.1 | 0.078 | 0.075 | 3 | 0.1 | 0.3
R1,R2,R3 | 3 | Gate current limiter | ERJ-2GEJ151X | Mouser | 1 |  | 0.08 | 0.012 | 0.012 | 0.005 | 9 | 0.08 | 0.72
R4 | 1 | Red LED voltage matching | PR02000201509JR500 | Mouser | 1 |  | 0.1 | 0.1 | 0.1 | 0.062 | 3 | 0.1 | 0.3
R5,R6,R7 | 3 | MOSFET gate pull-down | ERJ-2GEJ104X | Mouser | 1 |  | 0.08 | 0.012 | 0.012 | 0.005 | 9 | 0.08 | 0.72
Q1,Q2,Q3 | 3 | MOSFET | SI2302CDS-T1-E3 | Mouser | 1 |  | 0.15 | 0.14 | 0.14 | 0.13 | 9 | 0.15 | 1.35
 | 1 | PCB |  | OSH Park | 3 |  | 1 | 1 | 1 | 1 | 3 | 1 | 3

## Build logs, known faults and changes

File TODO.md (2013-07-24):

shopping list
--------------

* some other MCUs for testing

explore alternatives
---------------------

waterproof modular jacks are obscenely expensive.  consider possible alternative comms and power soures:

* zigbee
* wifi
* bluetooth
* powerline
* rs-485, power over cat5

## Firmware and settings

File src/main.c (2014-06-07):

#include <avr/sleep.h>
#include <pt.h>

#include "debug.h"

#include "board.h"
#include "ir.h"
#include "xbee.h"

int main(void)
{
    init_board();
    init_debug_subsystem();
    
    dprintf("booted in debug mode\r\n");
    
    struct pt xbee_pt; PT_INIT(&xbee_pt);
    struct pt ir_pt;   PT_INIT(&ir_pt);
    
    while(1) {
        xbee_task(&xbee_pt);
        ir_task(&ir_pt);
        
        sleep_mode();
    }
}

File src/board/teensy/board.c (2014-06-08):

/// \file teensy/board.c
///
/// Board-specific setup and peripheral driver code for Dave's
/// teensy-based (specifically, teensy 2.0) prototype.
///
/// Board overview:
///  pin mapping quick reference:
///      https://www.pjrc.com/teensy/card2a.pdf
///  schematic:
///      https://www.pjrc.com/teensy/schematic2.gif
/// 
/// Usage details 
///
/// Board has a 16 MHz crystal.  Clock starts up with divider 
/// set to 8, so we start by switching divider to 1.
/// 
/// Peripheral usage:
///
/// * Timer1 - PWM channels for LED output.
/// * Timer3 - IR input capture and timing
/// * USART1 - XBee
///
/// Pin usage:
/// 
/// * PB5/6/7: LED PWM output
/// * PC7: IR input
/// * PD2/3: xbee RX/TX, respectively
/// * PD6: status LED (on teensy board)
///

#include "board.h"

#include "ir.h"
#include "linearize.h"
#include "xbee.h"

#include <avr/io.h>
#include <avr/interrupt.h>

static void setup_clock();
static void setup_ir_pin();
static void setup_light_pins();
static void setup_xbee_uart();

#define ENABLE_STATUS_LED       do {DDRD |= 1 << DDD6;} while(0)
#define SET_STATUS_LED(on)      do {PORTD = (PORTD & ~(1 << PIND6)) | ((on ? 1 : 0) << PIND6);} while(0)

/// Setup the clock and all peripherals and interrupts used by the
/// teensy to implement functionality used by the board-independent
/// code in "src" 
void init_board(void) {
    setup_clock();
    
    setup_ir_pin();
    setup_light_pins();
    setup_xbee_uart();
    
    // enable onboard LED output so we can blink it suggestively
    ENABLE_STATUS_LED;
    
    sei();
}

/// teensy starts up in CLKDIV8 mode (2 MHz).
/// all we need to do here is switch out of it.
static void setup_clock() {
    CLKPR = 0b10000000; // enable changing the clock prescaler
    CLKPR = 0b00000000; // execute the change
}

/// the IR edge being waited for (this chip only
/// supports input capture for one edge at a time,
/// so we have to switch it back and forth).
/// 
/// \todo consider switching to a general pin-change
///       interrupt, we probably don't really need hardware
///       input capture.  the one benefit of using the timer
///       peripheral for this is that we can use the hardware
///       debouncing, but I think the IR module already does
///       some pretty aggressive noise filtering.  Dual-edge
///       interrupt sources to consider: INT0 on PD0, INT1
///       on PD1, or PCINT0:7 on PB0:7.  Alternatively,
///       consider relaxing IR parser to only time from
///       pulse to pulse, ignoring pulse widths) 
static bool rising_edge = false;

/// set up input to read IR sensor on PC7
/// and Timer3 to tick 64 usec, interrupt on pin change,
/// and interrupt twice during the cycle as well.
static void setup_ir_pin() {
    // set IR pin to input
    DDRC &= ~(1 << DDC7);
    
    // Timer3 configuration
    const uint8_t COM  = 0b00;   // no PWM
    const uint8_t WGM  = 0b0000; // Normal mode
    const uint8_t CS   = 0b101;  // 1:1024 with IO clock (15.625 kHz, period 64 µs)
    const uint8_t ICNC = 0b1;    // input-capture noise canceler enabled
    const uint8_t ICES = 0b0;    // initially looking for falling edge.
    
    // apply configuration
    TCCR3A
        = (COM              << COM3A0)
        | (COM              << COM3B0)
        | (COM              << COM3C0)
        | ((WGM & 0b0011)   << WGM30);
    TCCR3B
        = ((WGM >> 2)       << WGM32)
        | (CS               << CS30)
        | (ICES             << ICES3)
        | (ICNC             << ICNC3);
    rising_edge = ICES;
    
    // enable interrupts
    TIMSK3
        = 1 << ICIE3
        | 1 << TOIE3;
}

/// IR input pin changed
ISR(TIMER3_CAPT_vect) {
    bool     irdata     = !rising_edge;
    uint16_t event_time = ICR3;
    
    // reset the timer
    TCNT3 = 0;
    
    // switch the edge mode
    rising_edge = !rising_edge;
    TCCR3B = (TCCR3B & ~(1 << ICES3))
           | ((rising_edge ? 1 : 0) << ICES3);
    
    // report the event
    SET_STATUS_LED(irdata);
    ir_pin_changed(irdata, event_time);
}

/// IR input pin didn't change for a full timer cycle
ISR(TIMER3_OVF_vect) {
    ir_pin_watchdog_timeout();
}
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

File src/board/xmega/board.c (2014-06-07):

#include <avr/interrupt.h>

#include "ir.h"
#include "linearize.h"
#include "xbee.h"

ISR(TCC5_OVF_vect)
{
    // Read IR pin
    uint8_t irdata = !(PORTC.IN & PIN4_bm);
    
    // Clear interrupt
    TCC5.INTFLAGS = TC5_OVFIF_bm;
    
    // TODO: switch to input-capture like teensy version
    static uint16_t time       = 0;
    static bool old_irdata     = false;
    
    time++; // One more 50us tick
    if (time == 0xFFFF) {
        ir_pin_watchdog_timeout();
    }
    
    if (irdata != old_irdata) {
        ir_pin_changed(irdata, time);
        old_irdata = irdata;
        time = 0;
    }
}

#define BAUD 9600

ISR(USARTC0_RXC_vect) {
        // read status and byte immediately
    uint8_t status  = USARTC0.STATUS;
    uint8_t in_byte = USARTC0.DATA;
    
    xbee_byte_received(in_byte, status & USART_FERR_bm);
}

// #define USE_EXTERNAL_CLOCK

static void setup_clock() {
#ifdef USE_EXTERNAL_CLOCK
    // Configure, enable, and wait for crystal
    OSC.XOSCCTRL = OSC_FRQRANGE_12TO16_gc | OSC_XOSCSEL_XTAL_16KCLK_gc;
    OSC.CTRL |= OSC_XOSCEN_bm;
    while(!(OSC.STATUS & OSC_XOSCRDY_bm));
    
    // Configure, enable, and wait for 2x PLL
    OSC.PLLCTRL = OSC_PLLSRC_XOSC_gc | (2 << OSC_PLLFAC_gp);
    OSC.CTRL |= OSC_PLLEN_bm;
    while(!(OSC.STATUS & OSC_PLLRDY_bm));
    
    // Switch clock source to PLL output
    CCP = CCP_IOREG_gc;
    CLK.CTRL = CLK_SCLKSEL_PLL_gc;
#else
    CCP = CCP_IOREG_gc;              // disable register security for oscillator update
    OSC.CTRL = OSC_RC32MEN_bm;       // enable 32MHz oscillator
    while(!(OSC.STATUS & OSC_RC32MRDY_bm)); // wait for oscillator to be ready
    CCP = CCP_IOREG_gc;              // disable register security for clock update
    CLK.CTRL = CLK_SCLKSEL_RC32M_gc; // switch to 32MHz clock
#endif
}

static void setup_ir_pins() {
    // Ensure IR pin is set as input
    PORTC.DIRCLR = 0b1000;
    
    // set up TCC5 to give an interrupt every 50 usec (1600 cycles @ 32MHz)
    TCC5.CTRLB = 0b000 << TC5_WGMODE_gp;
    TCC5.CTRLC = 0;
    TCC5.CTRLD = 0;
    TCC5.CTRLE = 0;
    
    TCC5.PER = 1600;
    
    // enable TCC5_OVF_vect interrupt at LOW priority
    TCC5.INTCTRLA = 0b01 << TC5_OVFINTLVL_gp;
    
    // start the timer
    TCC5.CTRLA = 0b0001 << TC5_CLKSEL_gp;
}

static void setup_light_pins() {
    // Set OC0A/OC0B
    PORTC.DIRSET |= 0b00000111;
    
    // Set up 3-channel 16-bit dual-slope pwm on PORTC 0-2
    TCC4.PER = 0xFFFF;
    
    TCC4.CTRLB = 0b110 << TC4_WGMODE_gp;
    TCC4.CTRLC = TC4_POLA_bm | TC4_POLB_bm | TC4_POLC_bm;
    TCC4.CTRLD = 0;
    TCC4.CTRLE = (0b01 << TC4_CCAMODE_gp)
               | (0b01 << TC4_CCBMODE_gp)
               | (0b01 << TC4_CCCMODE_gp);
    
    TCC4.CCA = 0;
    TCC4.CCB = 0;
    TCC4.CCC = 0;
    
    // start the timer
    TCC4.CTRLA = 0b0001 << TC4_CLKSEL_gp;
}

void apply_light_values(uint16_t r, uint16_t g, uint16_t b) {
    TCC4.CTRLGSET = TC4_LUPD_bm;
    
    TCC4.CCABUF = r;
    TCC4.CCCBUF = g;
    TCC4.CCBBUF = b;
    
    linearize(
        &TCC4.CCABUF,
        &TCC4.CCCBUF,
        &TCC4.CCBBUF);
    TCC4.CTRLGCLR = TC4_LUPD_bm;
}

static void setup_xbee_uart() {
    // TODO: something semi-automatic
    #define BSEL    12
    #define BSCALE  4
    #define USE_2X  0
    
    PORTC.REMAP |= PORT_USART0_bm;
    
    USARTC0.CTRLA = USART_RXCINTLVL_MED_gc;
    USARTC0.CTRLB = USE_2X ? USART_CLK2X_bm : 0;
    USARTC0.CTRLC = USART_CMODE_ASYNCHRONOUS_gc 
                  | USART_PMODE_DISABLED_gc
                  | USART_CHSIZE_8BIT_gc;
    
    USARTC0.BAUDCTRLA = BSEL;
    USARTC0.BAUDCTRLB = (BSEL >> 8) | (BSCALE << 4);
    
    USARTC0.CTRLB |= USART_RXEN_bm;
}

void init_board(void) {
    setup_clock();
    
    setup_ir_pins();
    setup_light_pins();
    setup_xbee_uart();
    
    // Enable interrupts (first, the specific interrupt levels 
    // we care about - that is, all of them - then the global
    // interrupt flag)
    PMIC.CTRL = PMIC_LOLVLEN_bm | PMIC_MEDLVLEN_bm | PMIC_HILVLEN_bm;
    sei();
}

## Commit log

2013-06-10 added hardware schematic
    [DMX512 RGB LED.sch]
2013-06-18 inverted pwm mode, slight change to 'main'
    [lights.c, main.c]
2013-06-22 re-inverted, more playing with main
    [lights.c, main.c]
2013-06-22 switch to "phase-correct" pwm
    [lights.c]
2013-06-23 quick and ugly 16-bit software PWM
    it's actually a dynamic timer system, probably don't need the full generality for this project.
2013-06-23 Slimmed program down quite a bit by dropping the general-purpose timer stuff
    TIMER1 now only drives a 16-bit PWM system (but still provides a 16-bit unmolested time source)
2013-07-24 experimental xbee interface
    turns out wireless is about as much $ as weatherproof connectors...
    looking into options in that direction.
2013-08-04 added updated schematic
    [xbee rgb led.sch]
2013-08-04 fix wrong import in main.c
    [main.c]
2013-08-04 changed clock frequency to 8 MHz...
    ... so we can run at 3.3v. Final version will probably be 10MHz.
2013-08-11 moved schematics around a bit, added some new ones
    technically the xbee one isn't a functional prototype, but it's a very
    conservative change to the current breadboard version. The current
    version is as described there except it's still running on the
    attiny2313a at 5V - though it is running fine at 8MHz, so switching to
    3.3v should be no problem.
    [DMX512 RGB LED.sch, xbee rgb led.sch]
2013-08-11 Added Xmega A4U based concept schematic and pcb layout
    the layout is pretty ugly, but can probably be saved by making the crystal smaller and giving up on the expansion header (or reducing its size by quite a bit).
    [xmega-a4u.sch]
2013-08-11 Added schematic for a standalone power section
    This is pretty quick and dirty but i like how it turned out so I've ordered a few. Should be handy for trying out various SMD transistor and regulator options, and should also make a nice standalone 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
    [standalone-power-section.sch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]
2013-08-11 moved text around a bit for legibility in a schematic
    [standalone-power-section.sch]
2013-08-11 added BOM for standalone power section.
    [bom.xlsx]
2013-08-23 fixed polarity of capacitors on schematic
    stupid mistake... did the schematic with unpolarized symbols and when i
    did the layout it happened to end up with the wrong orientation.
    [standalone-power-section.sch]
2013-08-23 BOM as a haskell source file
2013-08-23 swapped red and blue
    only updating the IR for now, the xbee channel order/frame format isn't
    really specified yet anyway
2013-08-23 more pcb revisions
    moved some labels around, removed thermal relief on non-pin ground
    connection vias
2013-08-25 Updated for XMEGA
    Converted light and ir-remote subsystems. Xbee temporarily disabled,
    need to get or cobble together an adapter board that doesn't assume
    it's talking to a 5V MCU
    [lights.c, main.c]
2013-08-26 updated xbee interface code for xmega
    also switched to a slightly different xmega chip on the breadboard
2013-08-31 updated a comment about enabling XMEGA interrupts
2013-08-31 docs for several parts currently in use
2013-09-03 upgraded red led voltage matching resistor in BOM
2013-09-03 implemented basic color correction
    partially corrects for nonlinearities introduced by the shared-driver
    setup
    [lights.c]
2013-09-03 removed some cruft in lighting.h
    notes and constants from the attiny soft-pwm version
2013-09-12 updated power board gerbers
    [standalone-power-section.bottom.gbr, standalone-power-section.bottommask.gbr, standalone-power-section.bottompaste.gbr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]
2013-09-12 moved xbee to different UART
2013-09-13 Schematic and layout for an XMEGA E5 based prototype
    This is probably about the size and shape the final version will be.
    [xmega-xbee-rgb-led.sch]
2013-09-13 rotated PDI header on prototype layout
2013-09-14 truncated the xbee footprint and exported gerbers
    [xmega-xbee-rgb-led.sch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]
2013-09-20 changed prototype channel pins to match current schematic
2013-09-20 added a BOM for current schematic
2013-09-23 Added an expansion connector to the rev 0.1 board
    [xmega-xbee-rgb-led.sch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]
2013-09-23 Moved xbee serial connection to pins used on latest schematic
2014-01-02 switched to XMEGA's internal oscillator
    latest prototype board doesn't have an external crystal
2014-01-02 moved "standalone power section" schematic out of "prototypes" subdir
    this is the power board in dave's final hardware
    [bom.xlsx, standalone-power-section.sch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]
2014-05-20 update for current avr-shake
2014-06-04 Hardware abstraction and initial port to cayuse's teensy-based prototype.
2014-06-05 cleaning up xmega/board.c
2014-06-05 implemented UART setup for teensy, haven't tested yet though.
2014-06-05 fixed teensy light off-mode and added linearization
    [board.c, lights.c]
2014-06-07 pulling more processing out of interrupt handlers (IR parsing in this case)
2014-06-07 IR interface only needs a watchdog at timer overflow
2014-06-07 playing with protothreads a bit more
    rewrote the hand-rolled state machine for parsing NEC IR codes as a linear protothread.
    it cost about 50 bytes of program space, but made for a very nice readable flow.
    (though the old one was pretty readable too if you grok state machines)
2014-06-07 cleaned up IR thread a bit
2014-06-07 another minor change in IR thread
2014-06-08 teensy/board.c: changing layout and adding some overview docs
    also added "doc" target using doxygen
